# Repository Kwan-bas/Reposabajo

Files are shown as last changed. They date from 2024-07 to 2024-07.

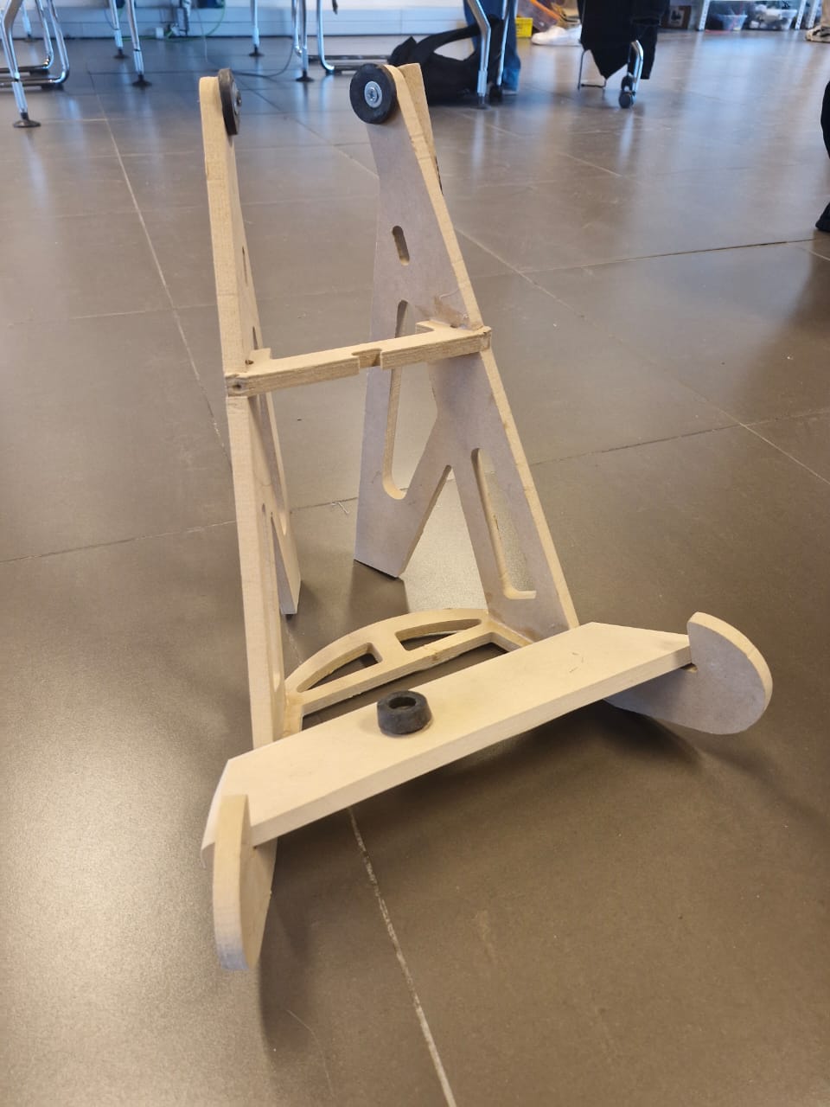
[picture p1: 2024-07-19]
Imagenes/Version-2.jpeg

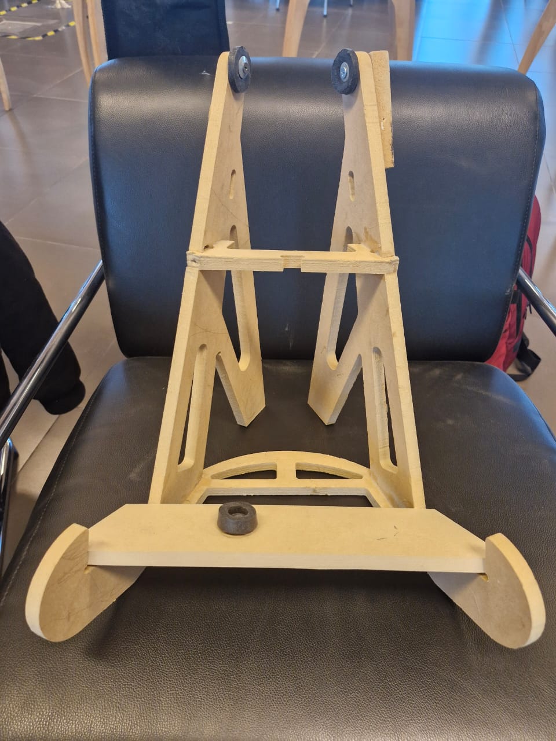
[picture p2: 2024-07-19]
Imagenes/version-2-frontal.jpeg

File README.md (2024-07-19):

## Reposabajo
Dispositivo para dejar reposando el bajo eléctrico. Diseño a la altura de los pies, para mayor versatilidad en posicionamiento en cualquier habitación. Modelo fue diseñado con la intención de ser fácilmente replicable mediante una máquina de corte CNC. Más información en carpeta de documentación.

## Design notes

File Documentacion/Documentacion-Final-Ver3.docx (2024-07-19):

# Reposa-bajo de piso.

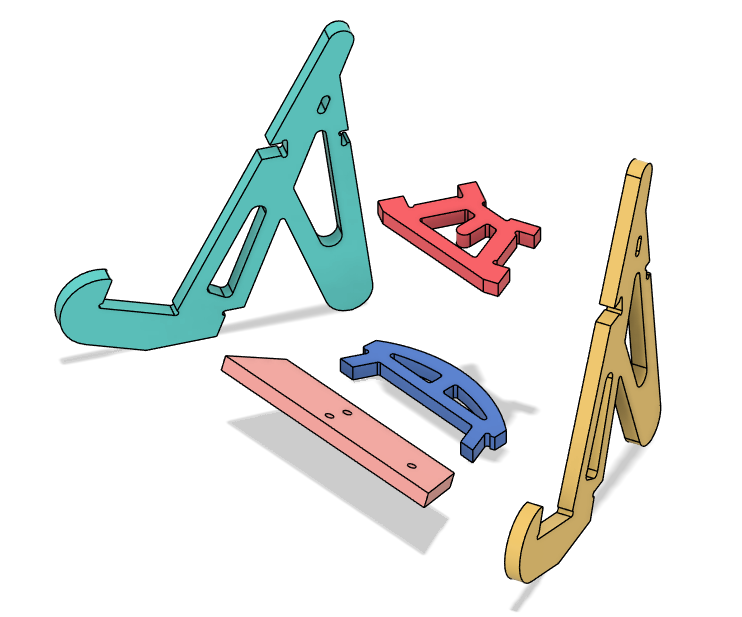
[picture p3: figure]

4

5

3

2

1

### Listado de partes:

1. Soporte izquierdo
2. Soporte Derecho
3. Unión Superior
4. Unión Inferior
5. Reposo

## Procesos de manufactura

La fabricación de los componentes se lleva al cabo a partir de un código G de contorneado, el cual se utiliza en una máquina de corte CNC.

Las principales características para su fabricación son:

- Plancha de madera terciada, espesor 18 mm. Se requiere una superficie total de 660x480 mm.
- Herramienta de corte tipo fresa de dos filos, diámetro de 6.35 mm y largo de filo de 20mm.
- Fijaciones con tornillos autoperforantes para madera de 1” de largo.
- Barniz para el sellado de las piezas.

El precio de la plancha de madera ronda los $22.000. Sus dimensiones son de 2440x1220 mm, por lo que se pueden extraer 8 copias del modelo, por lo que su precio por unidad queda en $2.750, sólo considerando precios de madera.

# Instrucciones de ensamble:

1. Levantar soportes izquierdo y derecho, ensamblar unión superior en cavidades superiores.

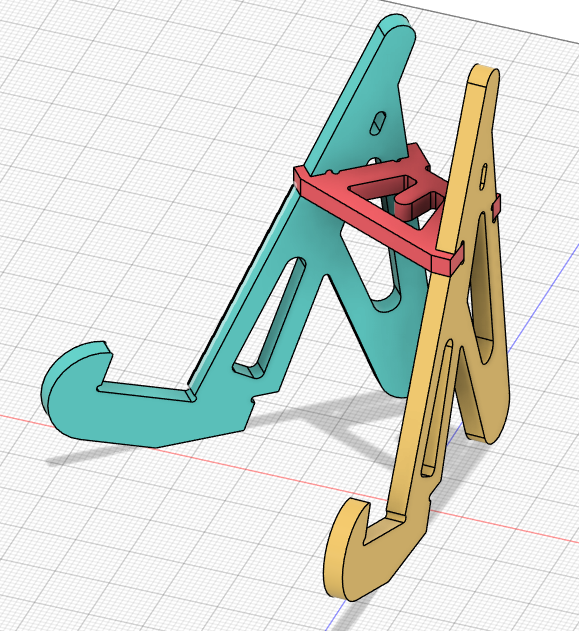
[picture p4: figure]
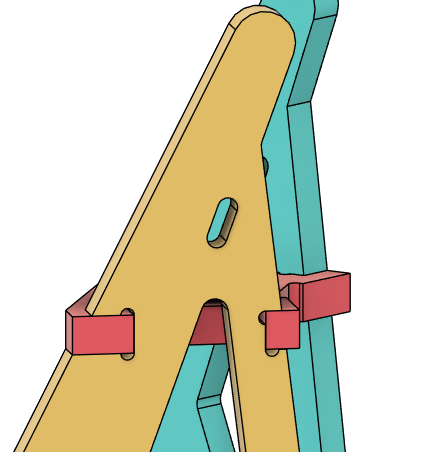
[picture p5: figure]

2. Insertar tornillos en uniones posteriores de la unión superior.

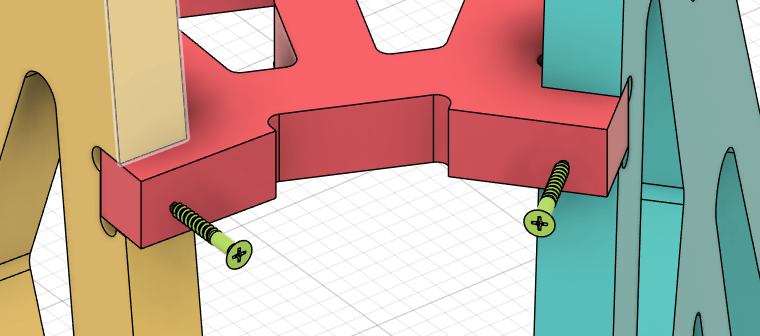
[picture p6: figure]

3. Ajustar unión inferior, alineando las caras mostradas e insertar tornillos en caras mostradas.

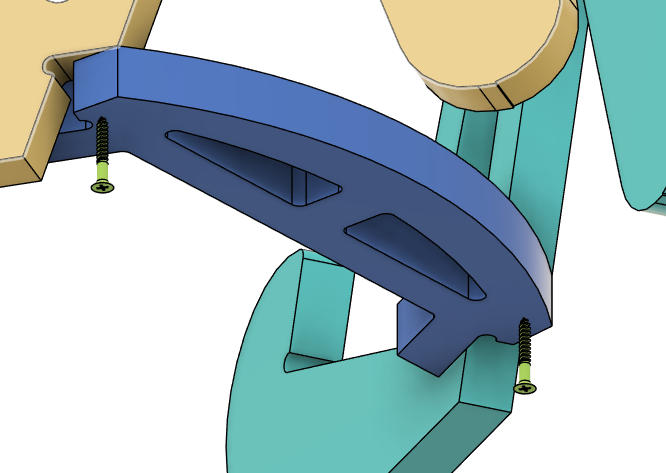
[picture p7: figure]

4. Finalmente, encajar reposo en los brazos de los soportes para luego atornillas en cada lado, como lo muestra la figura.

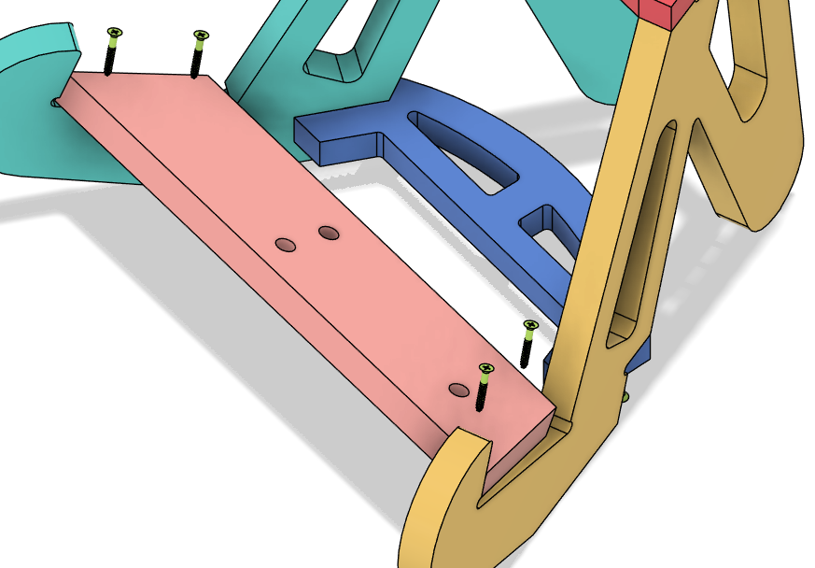
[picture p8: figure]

# Posibles mejoras para futuras versiones.

Las mejoras del prototipo abarcan condiciones de fabricación, uniones y materiales:

- Por una parte, las cavidades redondas que aseguran la perpendicularidad en la madera fuerzan a que componentes sean más frágiles, por lo que es indispensable por el momento usar el material descrito con el espesor asignado.
- Faltan partes de goma que faciliten la seguridad de dejar el bajo en el atril.
- Es posible iterar el diseño hasta una versión donde no sea necesaria el uso de tornillos, por lo que puede ser una motivación para futuras versiones.
- Formas podrían ser ajustados para agregar firmeza y estética al atril, existen simetrías redondas que pueden funcionar con el modelo

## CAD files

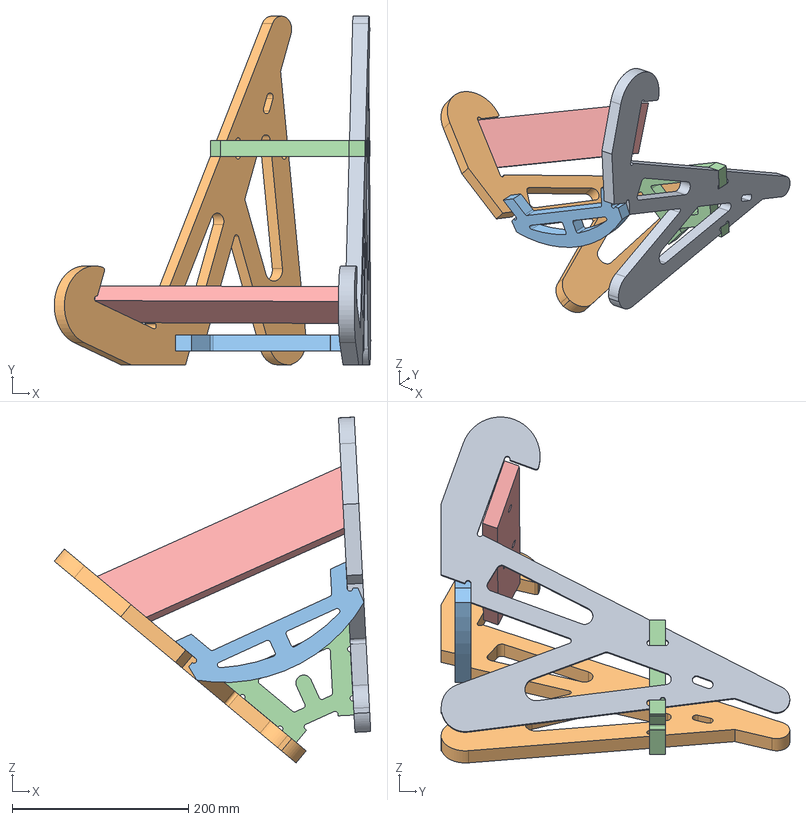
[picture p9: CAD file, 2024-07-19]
CAD/Ver3/Version-3-reposabajo.step
359.5 x 396.0 x 393.0 mm
Perfil Derecho
Perfil Izquierdo
Union Inferior
UNION SUPERIOR
ReposaBajo

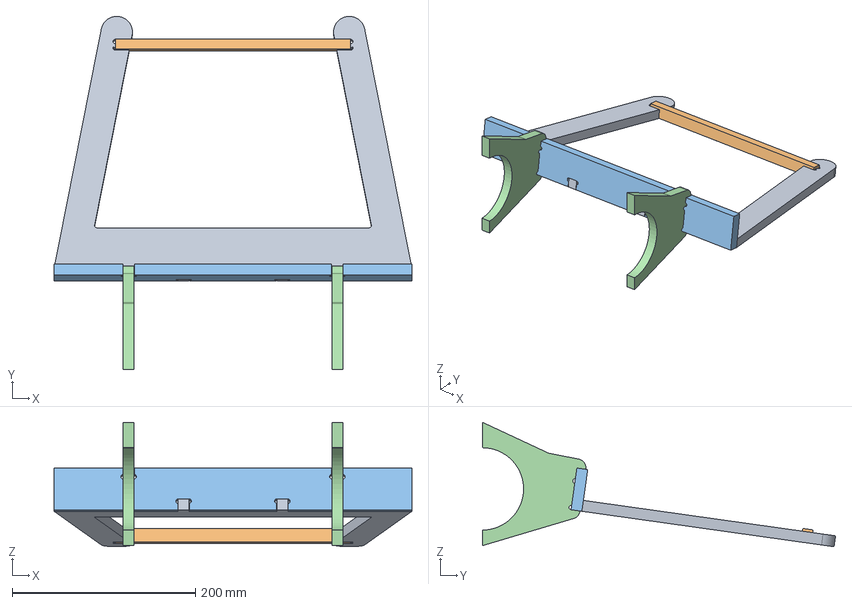
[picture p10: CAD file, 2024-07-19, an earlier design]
CAD/Ver1/Version-1-reposabajo.step
391.0 x 385.8 x 135.9 mm
Base Respaldo
Viga
Base
DER.
IZQ

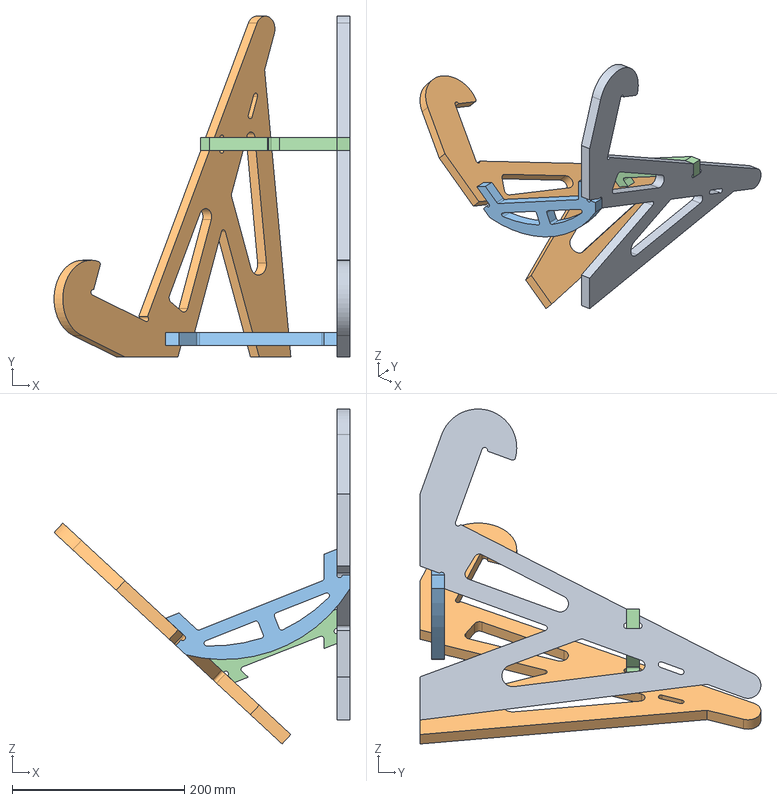
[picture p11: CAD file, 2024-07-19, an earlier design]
CAD/Ver2/Version-2-reposabajo.step
343.8 x 396.0 x 389.3 mm
Perfil Derecho
Perfil Izquierdo
Union Inferior
UNION SUPERIOR

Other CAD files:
CAD/Ver1/Version-1-reposabajo.f3z
CAD/Ver2/Version-2-reposabajo.f3z
CAD/Ver3/Version-3-reposabajo.f3d

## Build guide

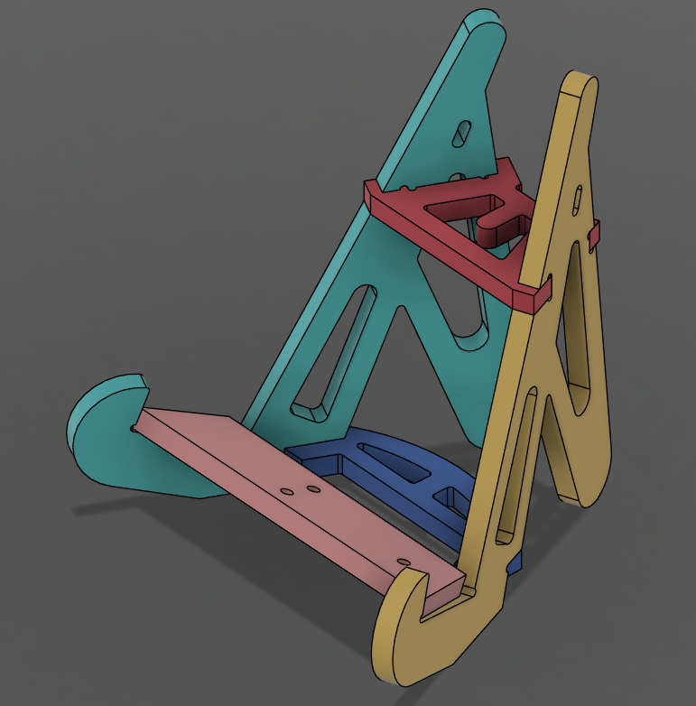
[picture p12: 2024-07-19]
Imagenes/Ensamble-final.png

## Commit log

2024-07-19 Imágenes para documentación
2024-07-19 Archivos CAD
    [Version-1-reposabajo.f3z, Version-1-reposabajo.step, Version-2-reposabajo.f3z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]
2024-07-19 Archivos CAD y G-Code utilizados y uno extra con fabricación total
